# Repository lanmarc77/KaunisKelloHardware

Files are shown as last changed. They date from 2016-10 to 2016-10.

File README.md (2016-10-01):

# KaunisKelloHardware
Hardware schematics of the Kaunis Kello clock

[firmware is here](https://github.com/lanmarc77/KaunisKello)

[firmware compiler](https://myiq.de/cgi-bin/kk.pl)

[hardware schematics are here](https://github.com/lanmarc77/KaunisKelloHardware)

[MP3 module code is here](https://github.com/lanmarc77/KaunisKelloSoundModule)

[SD card sounds of the MP3 module are here](https://github.com/lanmarc77/KaunisKelloSounds)

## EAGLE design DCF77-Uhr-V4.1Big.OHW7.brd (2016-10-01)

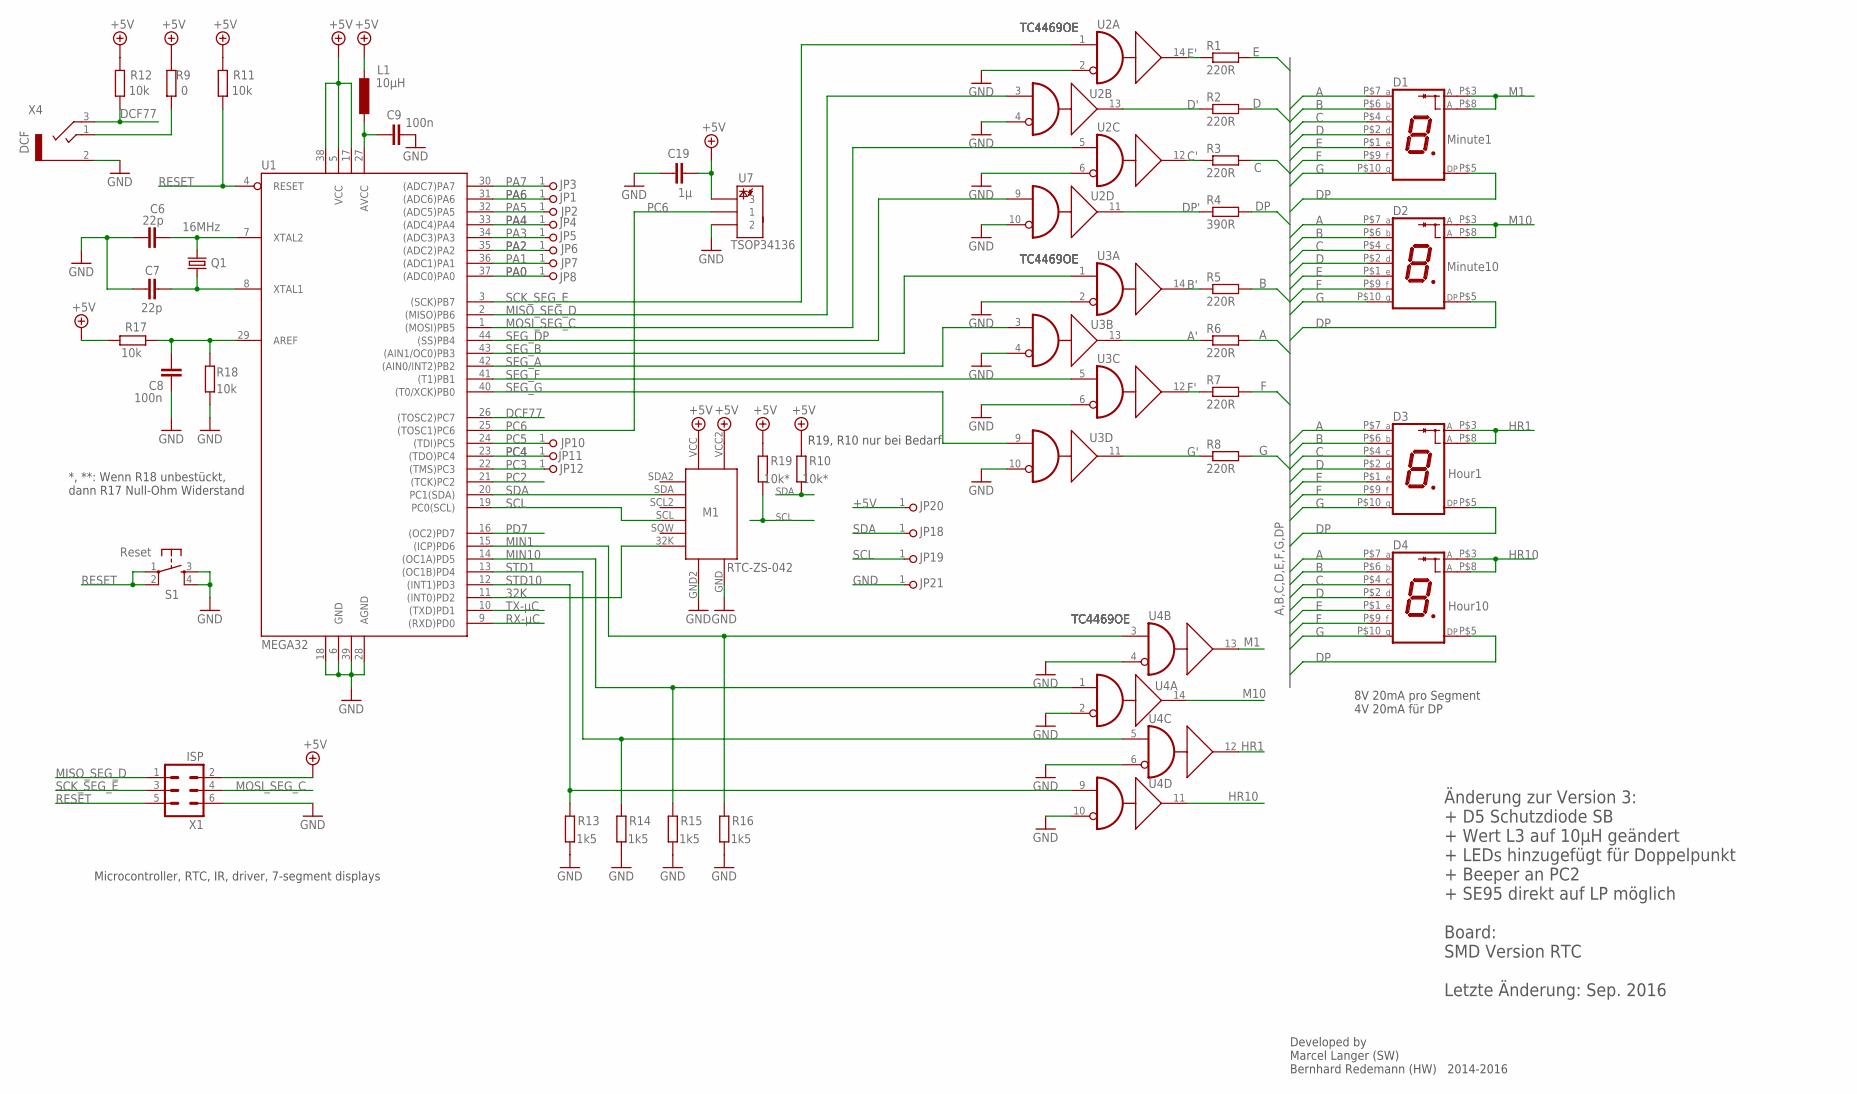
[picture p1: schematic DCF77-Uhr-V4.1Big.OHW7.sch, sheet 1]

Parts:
C6, C7: 22p; C0805
C8, C9: 100n; C0805
C19: 1µ; C0805
D1: Minute1; SA40-19EWA
D2: Minute10; SA40-19EWA
D3: Hour1; SA40-19EWA
D4: Hour10; SA40-19EWA
JP1, JP3: PA6; 1X01
JP2, JP10: PC5; 1X01
JP4: PA4; 1X01
JP5: PA3; 1X01
JP6: PA2; 1X01
JP7: PA1; 1X01
JP8: PA0; 1X01
JP11: PC4; 1X01
JP12: PC3; 1X01
JP18: SDA; 1X01
JP19: SCL; 1X01
JP20: +5V; 1X01
JP21: GND; 1X01
L1: 10µH; L2825P
M1: RTC-ZS-042; ZS-042-SMD
Q1: 16MHz; HC49UP
R1, R2, R3, R5, R6, R7, R8: 220R; M0805
R4: 390R; M0805
R9: 0; M0805
R10, R19: 10k*; M0805
R11, R12, R17, R18: 10k; M0805
R13, R14, R15, R16: 1k5; M0805
S1: Reset; DTSM-6
U1: MEGA32; TQFP44
U2, U3, U4: TC4469OE; SO-16DW
U7: TSOP34136; TSOP348
X1: ISP; ML6
X4: DCF; 1502_01

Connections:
32K: M1.32K, U1.11 ((INT0)PD2)
+5V: C19.2, JP20.1, L1.2, M1.VCC, M1.VCC2, R9.2, R10.2, R11.2, R12.2, R17.1, R19.2, U1.5 (VCC), U1.17 (VCC1), U1.38 (VCC2), U7.3, X1.2; also elsewhere on the board
A: D1.P$7 (A), D2.P$7 (A), D3.P$7 (A), D4.P$7 (A), R6.2
A': R6.1, U3.13 (Y)
AREF: C8.2, R17.2, R18.2, U1.29 (AREF)
B: D1.P$6 (B), D2.P$6 (B), D3.P$6 (B), D4.P$6 (B), R5.2
B': R5.1, U3.14 (Y)
C: D1.P$4 (C), D2.P$4 (C), D3.P$4 (C), D4.P$4 (C), R3.2
C': R3.1, U2.12 (Y)
D: D1.P$2 (D), D2.P$2 (D), D3.P$2 (D), D4.P$2 (D), R2.2
D': R2.1, U2.13 (Y)
DCF77: R12.1, U1.26 ((TOSC2)PC7), X4.3 (2)
DP: D1.P$5 (DP), D2.P$5 (DP), D3.P$5 (DP), D4.P$5 (DP), R4.2
DP': R4.1, U2.11 (Y)
E: D1.P$1 (E), D2.P$1 (E), D3.P$1 (E), D4.P$1 (E), R1.2
E': R1.1, U2.14 (Y)
F: D1.P$9 (F), D2.P$9 (F), D3.P$9 (F), D4.P$9 (F), R7.2
F': R7.1, U3.12 (Y)
G: D1.P$10 (G), D2.P$10 (G), D3.P$10 (G), D4.P$10 (G), R8.2
G': R8.1, U3.11 (Y)
GND: C6.1, C7.1, C8.1, C9.2, C19.1, JP21.1, M1.GND, M1.GND2, R13.1, R14.1, R15.1, R16.1, R18.1, S1.3, S1.4, U1.6 (GND), U1.18 (GND1), U1.28 (AGND), U1.39 (GND2), U2.2 (B), U2.4 (B), U2.6 (B), U2.10 (B), U3.2 (B), U3.4 (B), U3.6 (B), U3.10 (B), U4.2 (B), U4.4 (B), U4.6 (B), U4.10 (B), U7.2, X1.6, X4.2 (1); also elsewhere on the board
HR1: D3.P$3 (A), D3.P$8 (A), U4.12 (Y)
HR10: D4.P$3 (A), D4.P$8 (A), U4.11 (Y)
M1: D1.P$3 (A), D1.P$8 (A), U4.13 (Y)
M10: D2.P$3 (A), D2.P$8 (A), U4.14 (Y)
MIN1: R16.2, U1.15 ((ICP)PD6), U4.3 (A)
MIN10: R15.2, U1.14 ((OC1A)PD5), U4.1 (A)
MISO_SEG_D: U1.2 ((MISO)PB6), U2.3 (A), X1.1
MOSI_SEG_C: U1.1 ((MOSI)PB5), U2.5 (A), X1.4
unnamed: C6.2, Q1.2, U1.7 (XTAL2)
unnamed: C7.2, Q1.1, U1.8 (XTAL1)
unnamed: R9.1, X4.1 (3)
unnamed: C9.1, L1.1, U1.27 (AVCC)
PA0: JP8.1, U1.37 ((ADC0)PA0)
PA1: JP7.1, U1.36 ((ADC1)PA1)
PA2: JP6.1, U1.35 ((ADC2)PA2)
PA3: JP5.1, U1.34 ((ADC3)PA3)
PA4: JP4.1, U1.33 ((ADC4)PA4)
PA5: JP2.1, U1.32 ((ADC5)PA5)
PA6: JP1.1, U1.31 ((ADC6)PA6)
PA7: JP3.1, U1.30 ((ADC7)PA7)
PC2: U1.21 ((TCK)PC2); also elsewhere on the board
PC3: JP12.1, U1.22 ((TMS)PC3)
PC4: JP11.1, U1.23 ((TDO)PC4)
PC5: JP10.1, U1.24 ((TDI)PC5)
PC6: U1.25 ((TOSC1)PC6), U7.1
PD7: U1.16 ((OC2)PD7); also elsewhere on the board
RESET: R11.1, S1.1, S1.2, U1.4 (RESET), X1.5
RX-µC: U1.9 ((RXD)PD0); also elsewhere on the board
SCK_SEG_E: U1.3 ((SCK)PB7), U2.1 (A), X1.3
SCL: JP19.1, M1.SCL, R19.1, U1.19 (PC0(SCL)); also elsewhere on the board
SDA: JP18.1, M1.SDA, R10.1, U1.20 (PC1(SDA)); also elsewhere on the board
SEG_A: U1.42 ((AIN0/INT2)PB2), U3.3 (A)
SEG_B: U1.43 ((AIN1/OC0)PB3), U3.1 (A)
SEG_DP: U1.44 ((SS)PB4), U2.9 (A)
SEG_F: U1.41 ((T1)PB1), U3.5 (A)
SEG_G: U1.40 ((T0/XCK)PB0), U3.9 (A)
STD1: R14.2, U1.13 ((OC1B)PD4), U4.5 (A)
STD10: R13.2, U1.12 ((INT1)PD3), U4.9 (A)
TX-µC: U1.10 ((TXD)PD1); also elsewhere on the board

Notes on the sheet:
Microcontroller, RTC, IR, driver, 7-segment displays
Developed by Marcel Langer (SW) Bernhard Redemann (HW) 2014-2016
*, **: Wenn R18 unbestückt, dann R17 Null-Ohm Widerstand
8V 20mA pro Segment 4V 20mA für DP
R19, R10 nur bei Bedarf
Änderung zur Version 3: + D5 Schutzdiode SB + Wert L3 auf 10µH geändert + LEDs hinzugefügt für Doppelpunkt + Beeper an PC2 + SE95 direkt auf LP möglich Board: SMD Version RTC
Letzte Änderung: Sep. 2016

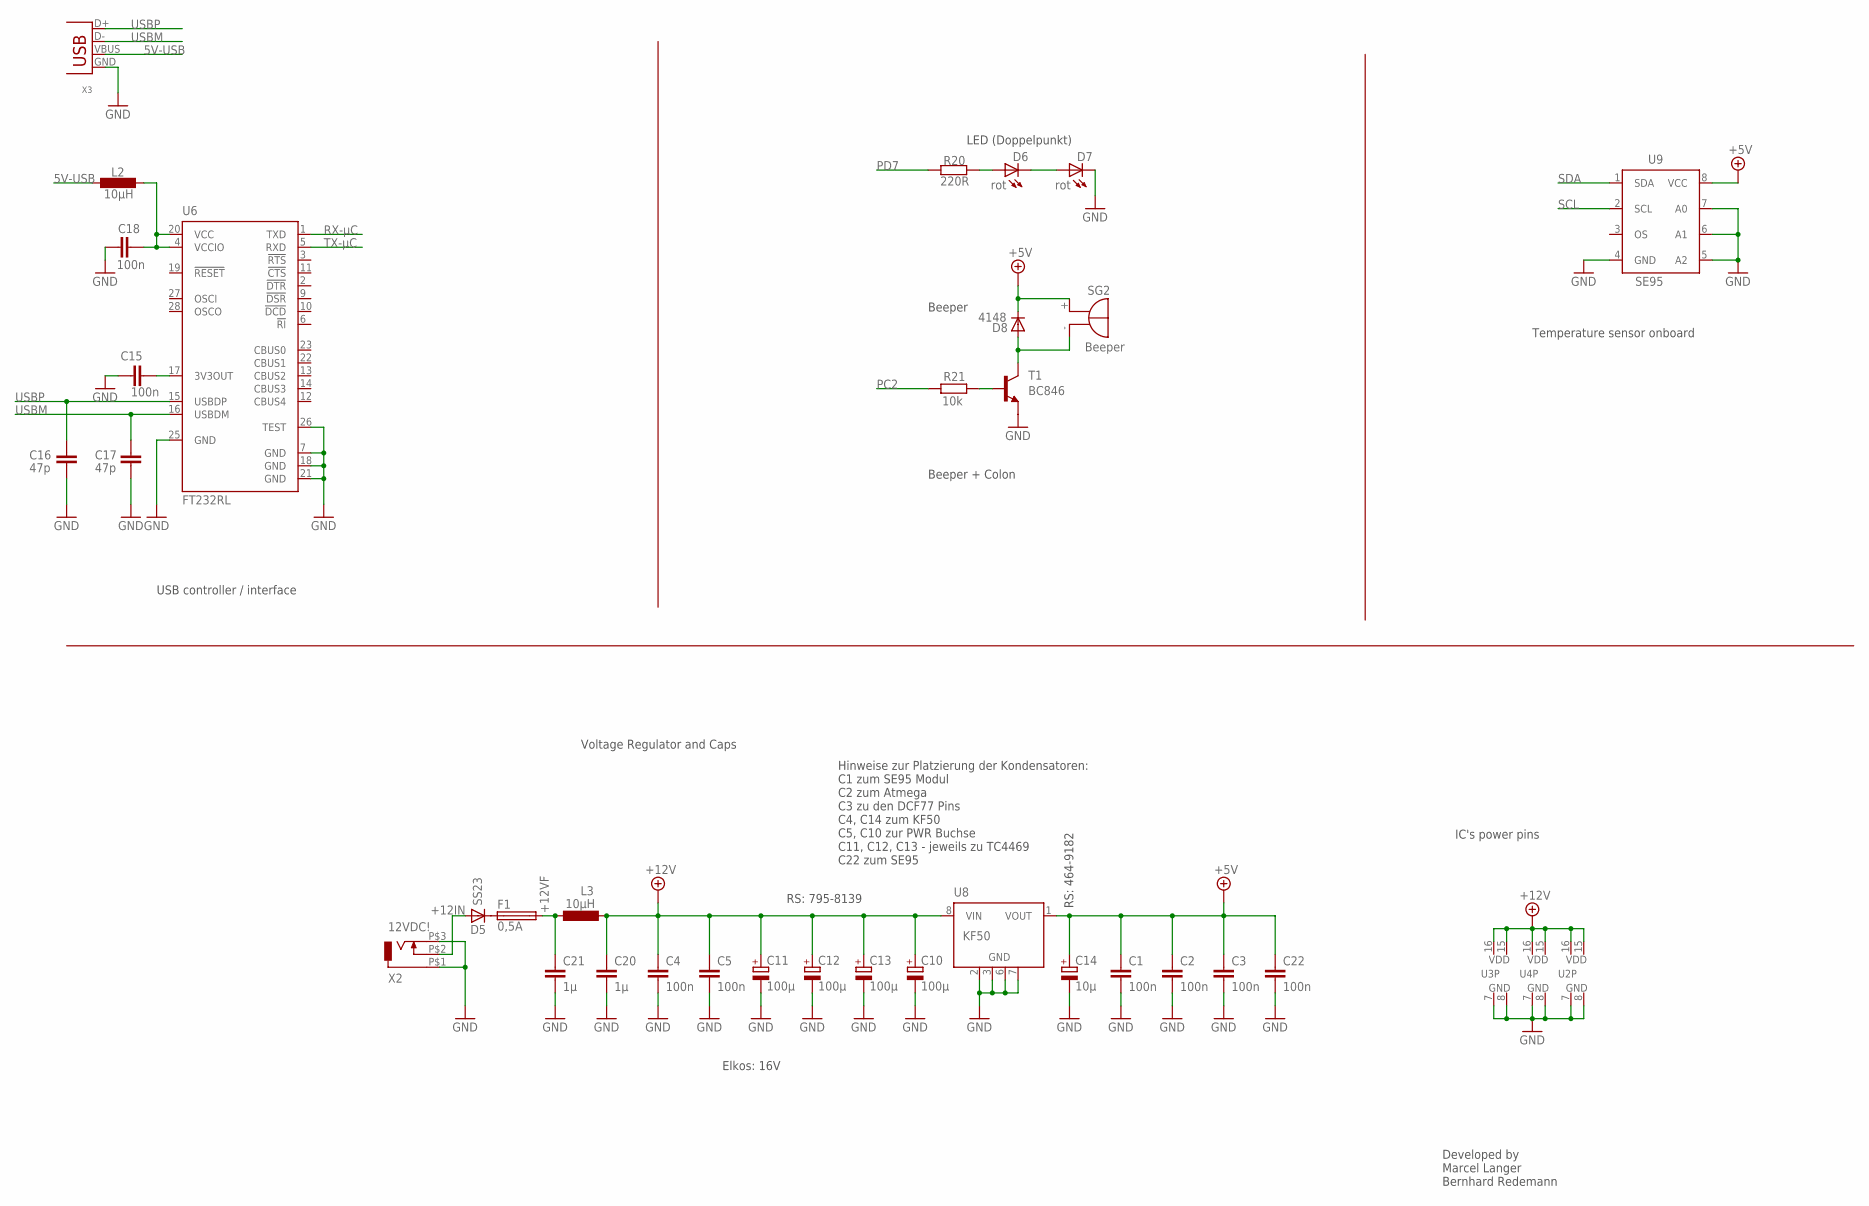
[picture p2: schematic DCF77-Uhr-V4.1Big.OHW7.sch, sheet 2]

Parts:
C1, C2, C3, C4, C5, C15, C18, C22: 100n; C0805
C10, C11, C12, C13: 100µ; PANASONIC_D
C14: 10µ; PANASONIC_B
C16, C17: 47p; C0805
C20, C21: 1µ; C0805
D5: SS23; SMB
D6, D7: rot; LED10MM
D8: 4148; DO214BA
F1: 0,5A; 19560
L2, L3: 10µH; L2825P
R20: 220R; M0805
R21: 10k; M0805
SG2: Beeper; BMT1205XH7.5
T1: BC846; SOT23
U2, U3, U4: TC4469OE; SO-16DW
U6: FT232RL; SSOP28
U8: KF50; SO08
U9: SE95; SO08
X2: 12VDC!; DCJ04-021
X3: USB; USB-B180

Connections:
5V-USB: L2.2, X3.VBUS
+5V: C1.1, C2.1, C3.1, C14.+, C22.1, D8.C, SG2.+, U8.1 (VOUT), U9.8 (VCC); also elsewhere on the board
+12IN: D5.A, X2.P$2 (2)
+12V: C4.1, C5.1, C10.+, C11.+, C12.+, C13.+, C20.1, L3.1, U2.15 (VDD), U2.16 (VDD), U3.15 (VDD), U3.16 (VDD), U4.15 (VDD), U4.16 (VDD), U8.8 (VIN)
+12VF: C21.1, F1.2, L3.2
GND: C1.2, C2.2, C3.2, C4.2, C5.2, C10.-, C11.-, C12.-, C13.-, C14.-, C15.1, C16.1, C17.1, C18.1, C20.2, C21.2, C22.2, D7.K (C), T1.2 (E), U2.7 (GND), U2.8 (GND), U3.7 (GND), U3.8 (GND), U4.7 (GND), U4.8 (GND), U6.7 (GND), U6.18 (GND), U6.21 (GND), U6.25 (GND), U6.26 (TEST), U8.2 (GND), U8.3 (GND), U8.6 (GND), U8.7 (GND), U9.4 (GND), U9.5 (A2), U9.6 (A1), U9.7 (A0), X2.P$1 (1), X2.P$3 (3), X3.GND; also elsewhere on the board
unnamed: D5.C, F1.1
unnamed: D6.A, R20.2
unnamed: D6.K (C), D7.A
unnamed: R21.1, T1.1 (B)
unnamed: D8.A, SG2.-, T1.3 (C)
unnamed: C15.2, U6.17 (3V3OUT)
unnamed: C18.2, L2.1, U6.4 (VCCIO), U6.20 (VCC)
PC2: R21.2; also elsewhere on the board
PD7: R20.1; also elsewhere on the board
RX-µC: U6.1 (TXD); also elsewhere on the board
SCL: U9.2 (SCL); also elsewhere on the board
SDA: U9.1 (SDA); also elsewhere on the board
TX-µC: U6.5 (RXD); also elsewhere on the board
USBM: C17.2, U6.16 (USBDM), X3.D-
USBP: C16.2, U6.15 (USBDP), X3.D+

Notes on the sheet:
USB controller / interface
Voltage Regulator and Caps
Hinweise zur Platzierung der Kondensatoren: C1 zum SE95 Modul C2 zum Atmega C3 zu den DCF77 Pins C4, C14 zum KF50 C5, C10 zur PWR Buchse C11, C12, C13 - jeweils zu TC4469 C22 zum SE95
Elkos: 16V
RS: 464-9182
RS: 795-8139
LED (Doppelpunkt)
Beeper
Temperature sensor onboard
Beeper + Colon
Developed by Marcel Langer Bernhard Redemann
IC's power pins

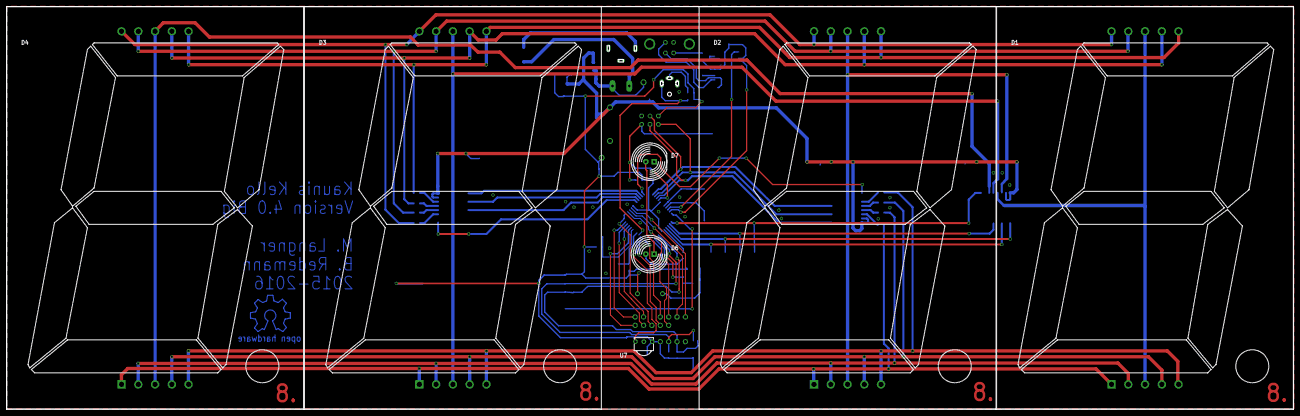
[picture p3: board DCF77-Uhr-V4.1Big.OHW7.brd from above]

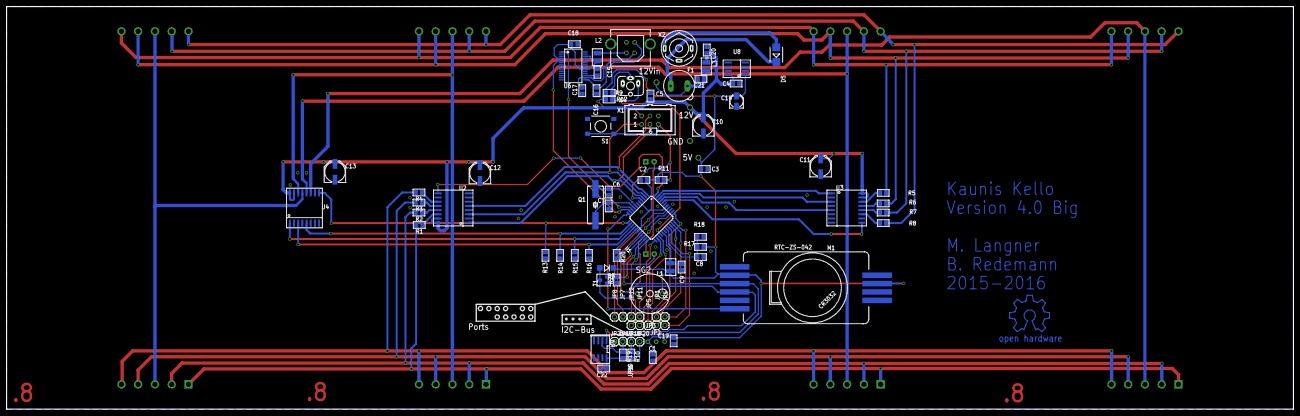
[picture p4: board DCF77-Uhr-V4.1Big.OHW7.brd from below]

Board: 2 copper layers, 390.0 x 122.0 mm, 88 parts (81 on the bottom side), 73 nets.

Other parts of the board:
U$1: OPEN_HARDWARE
